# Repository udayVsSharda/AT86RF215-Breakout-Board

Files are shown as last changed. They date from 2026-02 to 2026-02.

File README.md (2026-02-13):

# AT86RF215-Breakout-Board
AT86RF215 Breakout Board is a **4-layer controlled impedance board with JLCPCB's JLC04161H-3313 Stackup.**  AT86RF215xx is a fully integrated radio transceiver covering 389.5-510MHz / 779-1020MHz / 2400-2483.5MHz. It is configured using the SPI bus to receive and transmit while simultaneously operating the sub-1GHz and 2.4GHz radios.The impedance-matching filter are centered on 896MHz and 2450Mhz, so the design is optimized for the 2.4Ghz ISM and 900Mhz ISM bands. At 900MHz, transmit output power can be programmed upto +14dBm. The IQ interface with a sampling frequency of up to 4MHz gives it a decent bandwidth. I did not include manufacturing files(except BOM), but they can be easily obtained by following [JLCPCB Guide.](https://jlcpcb.com/help/article/how-to-generate-gerber-and-drill-files-in-kicad-9)  

[View the full PDF Schematic](https://github.com/udayVsSharda/AT86RF215-Breakout-Board/blob/main/Documents/Schematic%20AT86RF215%20Breakout-Board.pdf)

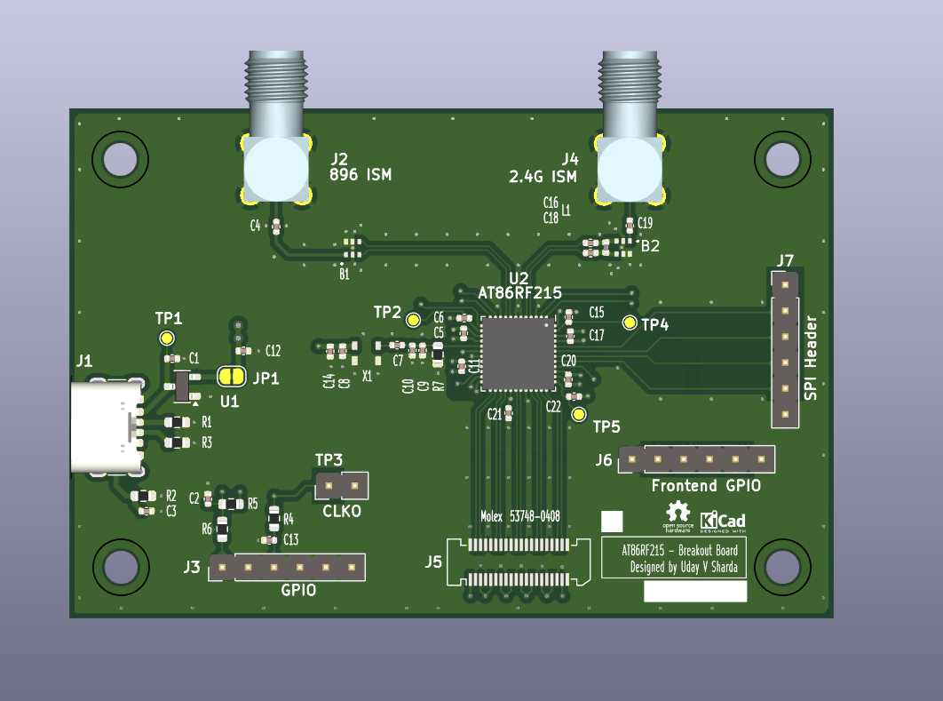
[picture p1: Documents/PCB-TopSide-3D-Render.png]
PCB Top-Side 3D-Render


## IQ Interface
It can also be configured for custom protocols using the 13-bit IQ Interface. Baseband PHY's transceiver can be completely bypassed by feeding IQ data directly to the DAC's using LVDS.The LVDS interface is based on the IEEE standard 1596.3 1996. The LVDS interface of the AT86RF215 has a data rate of 128Mb/s, composed of 16 data bits at 4MHz, for each of the I and Q data streams from the device. The LVDS uses double data rate (DDR), at a clock frequency of 64MHz. This flexibility makes it **useful for custom SDR Application.** The IQ interface can be accessed by soldering a **Molex Connector Part No. 53748-0408** connecting it ing board to board connector ** receptacle Molex Part No. 52991-0408** or similar 0.5mm pitch Board-to-Board Connectors.  

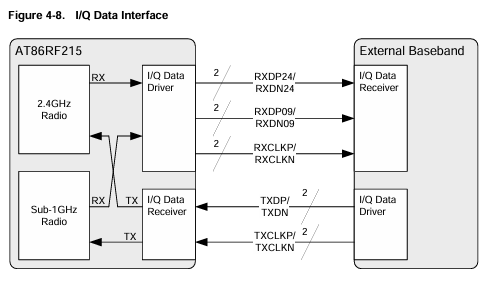
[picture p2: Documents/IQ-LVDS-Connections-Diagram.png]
LVDS IQ Connection Diagram


## Credit
[Uday Vivek Singh SHARDA](https://www.linkedin.com/in/uday-vivek-singh-sharda-988475122/)  
EENG2 P2029 ECAM LaSalle Lyon  
[KiCAD 8.0](https://www.kicad.org/)

## License
Hardware design files in this repository are licensed under the CERN-OHL-P-2.0 license.
See the LICENSE file for full terms.

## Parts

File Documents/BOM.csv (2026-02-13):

Comment | Designator | Footprint | JLCPCB Part#
0896BM15E0025001E | B1 | 0896BM15E0025 | C17271374
2450FB15A0050001E | B2 | 0896BM15E0025 | C17352285
1u | C1,C2,C6,C12,C15,C22 | C_0402_1005Metric | C52923
15p | C3,C8,C19 | C_0402_1005Metric | C1548
0.8p | C4 | C_0402_1005Metric | C88902
100n | C5,C11,C14,C17,C20,C21 | C_0402_1005Metric | C307331
1n | C7 | C_0402_1005Metric | C1523
1.8p | C9,C10,C13,C16,C18 | C_0402_1005Metric | C76903
USB_C | J1 | TYPE-C-6P | C19274014
5.8nH | L1 | L_0402_1005Metric | C576549
5.1k | R1,R3,R5 | R_0603_1608Metric | C23186
220 | R2,R4,R6 | R_0603_1608Metric | C22962
10k | R7 | R_0603_1608Metric | C2906982
XC6206P332MR-G | U1 | SOT-23-3 | C5446
AT86RF215 | U2 | JEDEC MO-220 VKKD-4 | C2151562
7L26002007 | X1 | 7L26002007 | C409249

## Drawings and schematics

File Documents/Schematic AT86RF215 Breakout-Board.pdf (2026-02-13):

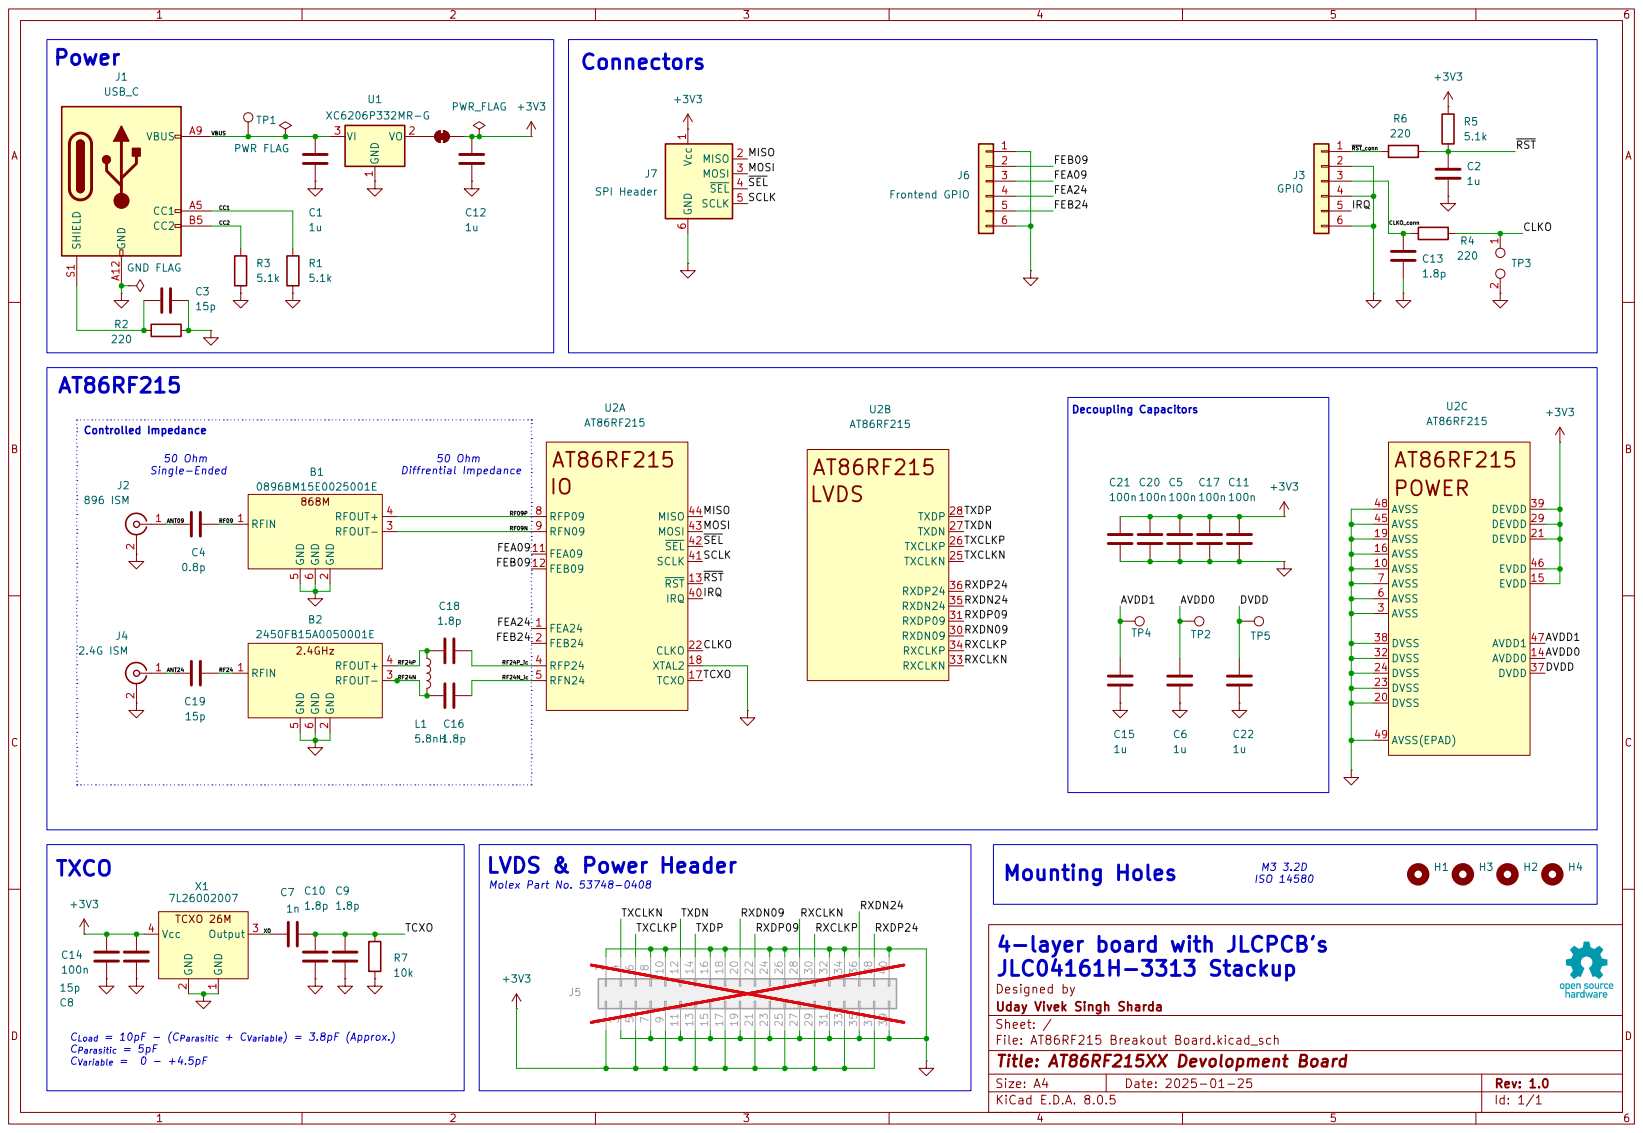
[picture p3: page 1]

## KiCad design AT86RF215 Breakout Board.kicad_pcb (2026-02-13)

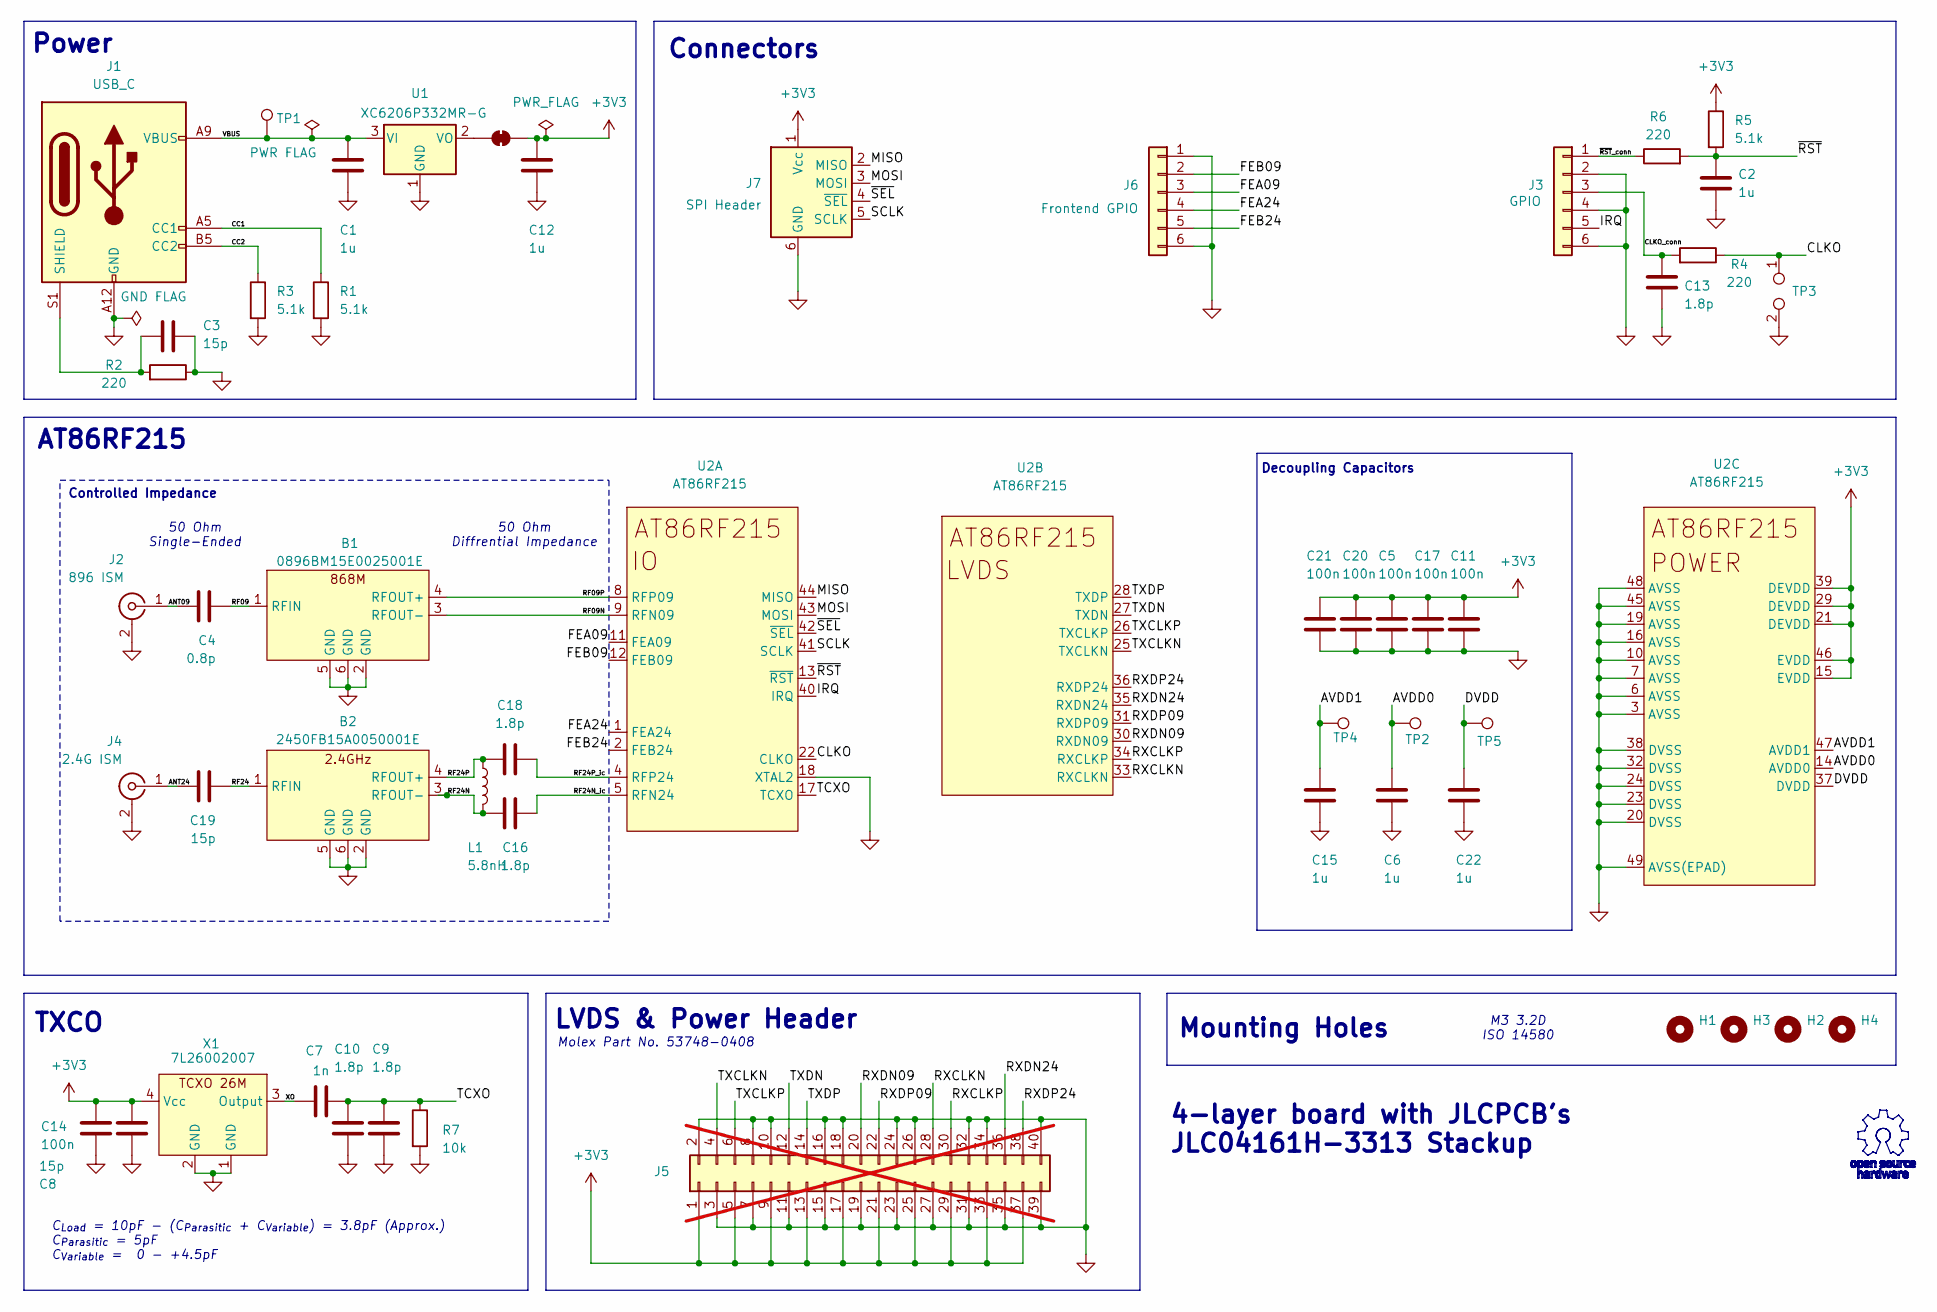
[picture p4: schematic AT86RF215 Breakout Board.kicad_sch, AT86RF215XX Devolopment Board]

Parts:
B1: 0896BM15E0025001E; 0896BM15E0025
B2: 2450FB15A0050001E; 0896BM15E0025
C1, C2, C6, C12, C15, C22: 1u; C_0402_1005Metric
C3, C8, C19: 15p; C_0402_1005Metric
C4: 0.8p; C_0402_1005Metric
C5, C11, C14, C17, C20, C21: 100n; C_0402_1005Metric
C7: 1n; C_0402_1005Metric
C9, C10, C13, C16, C18: 1.8p; C_0402_1005Metric
H1, H2, H3, H4: MountingHole; MountingHole_3.2mm_M3_ISO14580
J1: USB_C; USB_C_Receptacle_GCT_USB4125-xx-x-0190_6P_TopMnt_Horizontal
J2: 896 ISM; BWSMA-KE-Z001
J3: GPIO; PinHeader_1x06_P2.54mm_Vertical
J4: 2.4G ISM; BWSMA-KE-Z001
J5: Molex 53748-0408; Molex_SlimStack_53748-0408_2x20_P0.50mm_Vertical; not fitted
J6: Frontend GPIO; PinHeader_1x06_P2.54mm_Vertical
J7: SPI Header; PinHeader_1x06_P2.54mm_Vertical
JP1: SolderJumper_2_Bridged; SolderJumper-2_P1.3mm_Bridged_RoundedPad1.0x1.5mm
L1: 5.8nH; L_0402_1005Metric
R1, R3, R5: 5.1k; R_0603_1608Metric
R2, R4, R6: 220; R_0603_1608Metric
R7: 10k; R_0603_1608Metric
TP1: VBUS; TestPoint_Pad_D1.0mm
TP2: AVDD0; TestPoint_Pad_D1.0mm
TP3: CLKO; PinHeader_1x02_P2.54mm_Vertical
TP4: AVDD1; TestPoint_Pad_D1.0mm
TP5: DVDD; TestPoint_Pad_D1.0mm
U1: XC6206P332MR-G; SOT-23-3
U2: AT86RF215
X1: 7L26002007

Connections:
+3V3: C5.1, C8.2, C11.1, C12.1, C14.1, C17.1, C20.1, C21.1, J5.1, J5.5, J5.9, J5.13, J5.17, J5.21, J5.25, J5.29, J5.33, J5.37, J7.1 (Vcc), JP1.1 (A), R5.1, U2.15 (EVDD), U2.21 (DEVDD), U2.29 (DEVDD), U2.39 (DEVDD), U2.46 (EVDD), X1.4 (Vcc)
/ANT09: C4.2, J2.1 (In)
/ANT24: C19.2, J4.1 (In)
/AVDD0: C6.1, TP2.1, U2.14 (AVDD0)
/AVDD1: C15.1, TP4.1, U2.47 (AVDD1)
/CC1: J1.A5 (CC1), R1.1
/CC2: J1.B5 (CC2), R3.1
/CLKO: R4.1, TP3.1, U2.22 (CLKO)
/CLKO_conn: C13.2, J3.3, R4.2
/DVDD: C22.1, TP5.1, U2.37 (DVDD)
/FEA09: J6.3, U2.11 (FEA09)
/FEA24: J6.4, U2.1 (FEA24)
/FEB09: J6.2, U2.12 (FEB09)
/FEB24: J6.5, U2.2 (FEB24)
/IRQ: J3.5, U2.40 (IRQ)
/MISO: J7.2 (MISO), U2.44 (MISO)
/MOSI: J7.3 (MOSI), U2.43 (MOSI)
/RF09: B1.1 (RFIN), C4.1
/RF09N: B1.3 (RFOUT-), U2.9 (RFN09)
/RF09P: B1.4 (RFOUT+), U2.8 (RFP09)
/RF24: B2.1 (RFIN), C19.1
/RF24N: B2.3 (RFOUT-), C16.1, L1.2
/RF24N_ic: C16.2, U2.5 (RFN24)
/RF24P: B2.4 (RFOUT+), C18.1, L1.1
/RF24P_ic: C18.2, U2.4 (RFP24)
/RXCLKN: J5.28, U2.33 (RXCLKN)
/RXCLKP: J5.30, U2.34 (RXCLKP)
/RXDN09: J5.20, U2.30 (RXDN09)
/RXDN24: J5.36, U2.35 (RXDN24)
/RXDP09: J5.22, U2.31 (RXDP09)
/RXDP24: J5.38, U2.36 (RXDP24)
/SCLK: J7.5 (SCLK), U2.41 (SCLK)
/TCXO: C7.2, C9.2, C10.2, R7.1, U2.17 (TCXO)
/TXCLKN: J5.4, U2.25 (TXCLKN)
/TXCLKP: J5.6, U2.26 (TXCLKP)
/TXDN: J5.12, U2.27 (TXDN)
/TXDP: J5.14, U2.28 (TXDP)
/VBUS: C1.1, J1.A9 (VBUS), J1.B9 (VBUS), TP1.1, U1.3 (VI)
/XO: C7.1, X1.3 (Output)
/~RST: C2.1, R5.2, R6.2, U2.13 (~RST)
/~RST_conn: J3.1, R6.1
/~SEL: J7.4 (~SEL), U2.42 (~SEL)
GND: B1.2 (GND), B1.5 (GND), B1.6 (GND), B2.2 (GND), B2.5 (GND), B2.6 (GND), C1.2, C2.2, C3.2, C5.2, C6.2, C8.1, C9.1, C10.1, C11.2, C12.2, C13.1, C14.2, C15.2, C17.2, C20.2, C21.2, C22.2, J1.A12 (GND), J1.B12 (GND), J2.2 (Ext), J3.2, J3.4, J3.6, J4.2 (Ext), J5.2, J5.3, J5.7, J5.8, J5.10, J5.11, J5.15, J5.16, J5.18, J5.19, J5.23, J5.24, J5.26, J5.27, J5.31, J5.32, J5.34, J5.35, J5.39, J5.40, J6.1, J6.6, J7.6 (GND), R1.2, R2.1, R3.2, R7.2, TP3.2, U1.1 (GND), U2.3 (AVSS), U2.6 (AVSS), U2.7 (AVSS), U2.10 (AVSS), U2.16 (AVSS), U2.18 (XTAL2), U2.19 (AVSS), U2.20 (DVSS), U2.23 (DVSS), U2.24 (DVSS), U2.32 (DVSS), U2.38 (DVSS), U2.45 (AVSS), U2.48 (AVSS), U2.49 (AVSS(EPAD)), X1.1 (GND), X1.2 (GND)
unnamed: C3.1, J1.S1 (SHIELD), R2.2
unnamed: JP1.2 (B), U1.2 (VO)

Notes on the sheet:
LVDS & Power Header
Power
C_{Load} = 10pF - (C_{Parasitic} + C_{Variable}) = 3.8pF (Approx.) C_{Parasitic} = 5pF C_{Variable} = 0 - +4.5pF
Connectors
AT86RF215
50 Ohm Diffrential Impedance
TXCO
Controlled Impedance
50 Ohm Single-Ended
Decoupling Capacitors
4-layer board with JLCPCB's JLC04161H-3313 Stackup
Molex Part No. 53748-0408
M3 3.2D ISO 14580
Mounting Holes

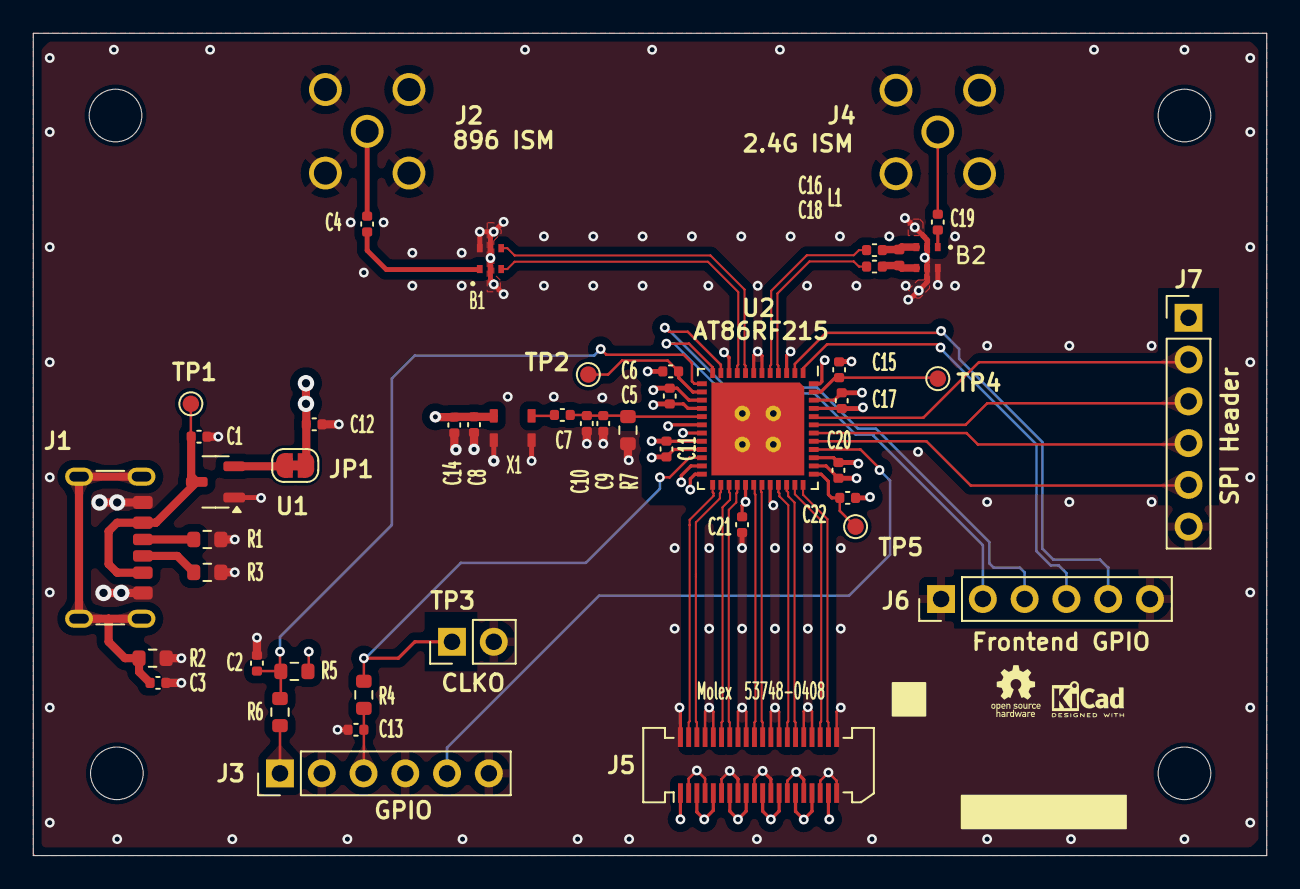
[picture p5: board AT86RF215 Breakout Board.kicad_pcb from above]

Board: 4 copper layers, 75.0 x 50.0 mm, 52 parts (0 on the bottom side), 45 nets.

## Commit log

2026-02-13 Rename AT86RF215 Breakout Board.pdf to Documents/AT86RF215 Breakout Board.pdf
2026-02-13 Rename AT86RF215 Breakout Board.pdf to PDF- Schematic AT86RF215 Breakout-Board.pdf
2026-02-13 Rename PDF- Schematic AT86RF215 Breakout-Board.pdf to PDF- Schematic AT86RF215 Breakout-Board.pdf
2026-02-13 Rename PDF- Schematic AT86RF215 Breakout-Board.pdf to Schematic AT86RF215 Breakout-Board.pdf
2026-02-13 added local symbol and footprint libs
    [AT86RF215 Breakout Board.kicad_pcb, AT86RF215 Breakout Board.kicad_sch]
